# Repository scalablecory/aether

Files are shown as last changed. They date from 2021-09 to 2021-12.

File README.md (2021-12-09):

# Aether



Aether is an air quality monitoring device and software, Open Source and powered by .NET 6.

Want to make your own? Check out the no-soldering-required [Hackathon 2021 build](builds/Hackathon%202021.md), pictured to the right.

## Features

- At-a-glance air quality monitoring with addressable RGB.
- Small standalone device with a custom 3D-printed case.
- No-solder plug-and-play hardware.

### Planned

- SD image for easy deployment.
- Monitor air quality over a Web Bluetooth enabled website.
- Monitor air quality over Bluetooth/WiFi via a .NET MAUI app.
- (Optionally) Join a WiFi network for multi-room monitoring.
- (Maybe) MQTT support.
- (Maybe) Zigbee / LoRa / LoRaWAN support.

## Contributing

Contributions are welcome. Please [contact me](https://github.com/scalablecory) with any questions. The desired workflow is:

1. File an issue describing the bug or desired enhancement.
2. If you intend to perform the work on an issue, ask for it to be assigned to you.
3. If the issue is for an enhancement, wait for it to be approved.
4. File a PR. Make sure to link the issue it will close in the top comment.

Aether could use contributions for:

- Web and mobile dev, for Bluetooth apps.
- Linux deployment (install instructions and/or SD image creation)
- Linux Bluetooth (need to make the Aether into a BLE device)
- Driver dev (C#).
- General .NET dev (C#).
- 3D modeling for case design.

## Hardware Support

- [Raspberry Pi](https://www.raspberrypi.org/) - 3B, 4B, and Zero 2
- [Waveshare 2.9" E-ink display](https://www.waveshare.com/product/displays/e-paper/epaper-2/2.9inch-e-paper-module.htm)
- [Sensirion SCD4x](https://www.sensirion.com/en/environmental-sensors/carbon-dioxide-sensors/carbon-dioxide-sensor-scd4x/) - CO<sub>2</sub>, temperature, relative humidity
- [Sensirion SHT4x](https://www.sensirion.com/en/environmental-sensors/humidity-sensors/humidity-sensor-sht4x/) - temperature, relative humidity
- [Sensirion SPS30](https://www.sensirion.com/en/environmental-sensors/particulate-matter-sensors-pm25/) - PM<sub>0.5</sub>, PM<sub>1.0</sub>, PM<sub>2.5</sub>, PM<sub>4</sub>, PM<sub>10</sub>
- [Sensirion SGP40](https://www.sensirion.com/en/environmental-sensors/gas-sensors/sgp40/) - VOC detector
- [TE MS5637](https://www.te.com/commerce/DocumentDelivery/DDEController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) - barometric pressure
- [Dongguan OPSCO Optoelectronics SK9822](https://www.opscoled.com/en/product/details.html?id=19) - Addressable RGB LED

## .NET Contributions

After being proven in Aether, drivers are contributed to [dotnet/iot](https://github.com/dotnet/iot/). So far, this has been:

- [Sensirion SCD4x](https://github.com/dotnet/iot/tree/main/src/devices/Scd4x) - CO<sub>2</sub>, temperature, relative humidity
- [Sensirion SHT4x](https://github.com/dotnet/iot/tree/main/src/devices/Sht4x) - temperature, relative humidity

# License

Aether is licensed under the [MIT license](https://opensource.org/licenses/MIT).

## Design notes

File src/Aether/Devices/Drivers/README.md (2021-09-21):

# Aether Sensor Drivers

These should be contributed to dotnet/iot repo once completed.

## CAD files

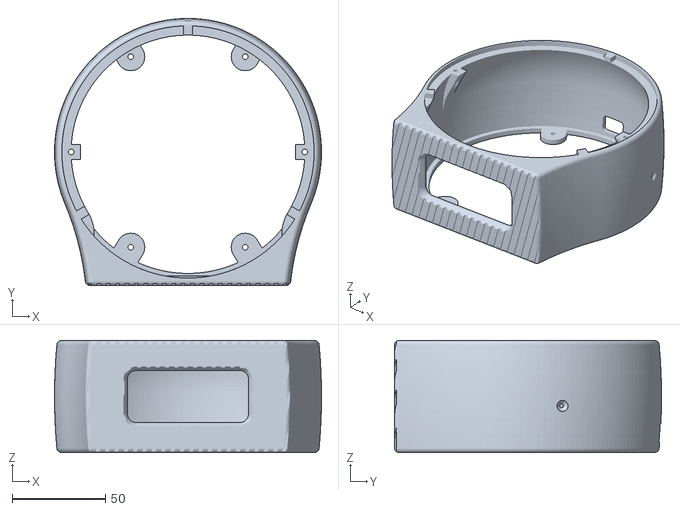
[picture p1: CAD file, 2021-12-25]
builds/Hackathon 2021/Body.stl
142.9 x 143.0 x 60.0

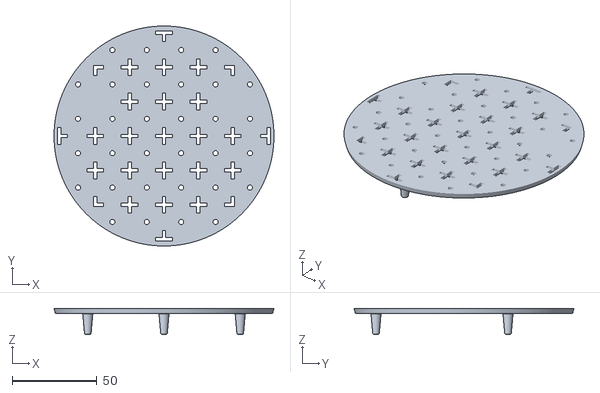
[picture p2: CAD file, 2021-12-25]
builds/Hackathon 2021/Base.stl
130.0 x 130.0 x 15.5

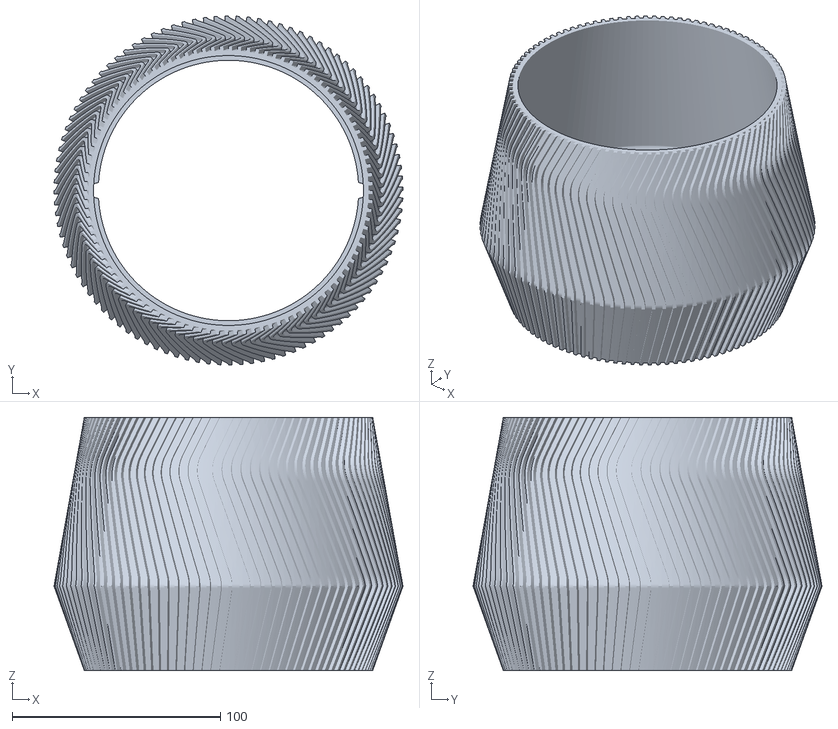
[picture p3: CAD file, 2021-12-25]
builds/Hackathon 2021/Baffle.stl
167.6 x 167.6 x 121.5

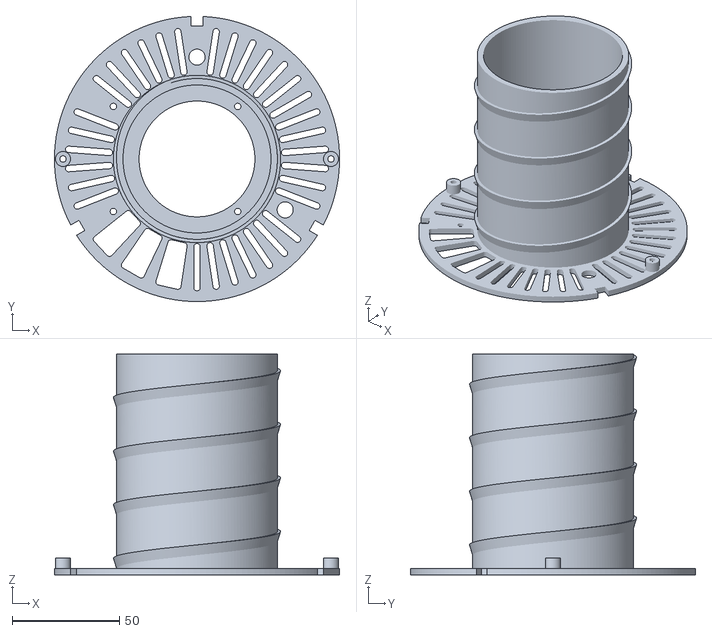
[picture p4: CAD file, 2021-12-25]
builds/Hackathon 2021/Pi holder.stl
133.0 x 132.9 x 103.0

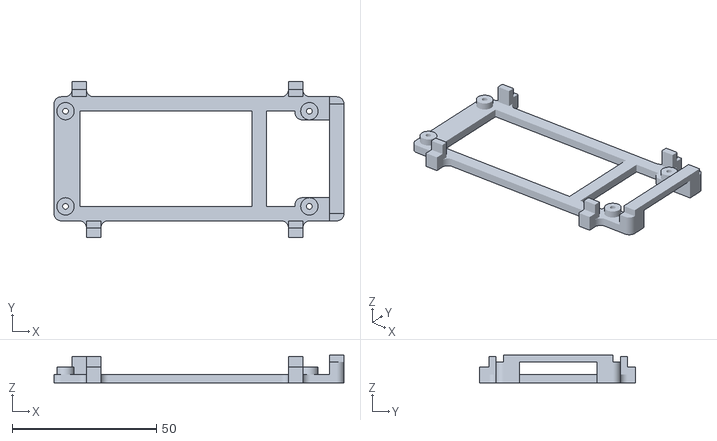
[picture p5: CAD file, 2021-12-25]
builds/Hackathon 2021/Display Bracket.stl
100.5 x 53.9 x 9.70

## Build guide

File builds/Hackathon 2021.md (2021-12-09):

# Hackathon 2021



This was created as part of Microsoft's [2021 Hackathon](https://garagehackbox.azurewebsites.net/hackathons/2356/projects/105003).

See a video of it in action to the right.<br clear="right" />

## Parts List

Parts are chosen to be plug and play, with no soldering required. This build uses the [Qwiic](https://www.sparkfun.com/qwiic) I<sup>2</sup>C wiring system to be very easy to piece together.

Sensors can be left off if uninterested in their measurements.

| Part | Description | Sparkfun Link | Adafruit Link
| ---- | --- | --- | ---
| Raspberry Pi 4 Model B 2GB | Main board. | [SF Pi 4](https://www.sparkfun.com/products/15446) | [AF Pi 4](https://www.adafruit.com/product/4292)
| Sensirion SCD40 | CO<sub>2</sub>, Relative Humidity, and Temperature sensor. | [SF SCD40](https://www.sparkfun.com/products/18365) | [AF SCD40](https://www.adafruit.com/product/5187)
| TE MS5637 | Barometric Pressure and Temperature sensor. Used to calibrate the SDC40. | [SF MS5637](https://www.sparkfun.com/products/14688)
| Sensirion SGP40 | VOC change sensor. | [SF SGP40](https://www.sparkfun.com/products/18345) | [AF SGP40](https://www.adafruit.com/product/4829)
| Sensirion SPS30 | PM<sub>0.5</sub>, PM<sub>1.0</sub>, PM<sub>2.5</sub>, PM<sub>4</sub>, and PM<sub>10</sub> sensor. | [SF SPS30](https://www.sparkfun.com/products/15103)
| [Waveshare 2.9" E-ink](https://www.waveshare.com/product/displays/e-paper/epaper-2/2.9inch-e-paper-module.htm) | A display to show measurements.

### Addressable RGB

To wire the LEDs, some breadboarding or soldering will be required.

Other than the LEDs themselves, these parts do not require software support. Feel free to mix and match.

| Part | Description | Mouser Link | Adafruit Link
| ---- | --- | --- | ---
| SK9822 / APA102C | Addressable RGB LEDs. | [SF APA102C](https://www.sparkfun.com/products/14015) | [AF SK9822](https://www.adafruit.com/product/2239?length=1)
| 3.3v to 5v level shifter, min two inputs | Converts signals from Pi's 3.3v to the LED's 5v. | [Mouser SN74AHCT125N](https://www.mouser.com/ProductDetail/595-SN74AHCT125N) | [AF SN74AHCT125N](https://www.adafruit.com/product/1787)
| Capacitor, min 5V 1000μF | To smooth out power demand of LEDs. | [Mouser ESW108M6R3AH1AA](https://www.mouser.com/ProductDetail/80-ESW108M6R3AH1AA)

## Operating System Setup

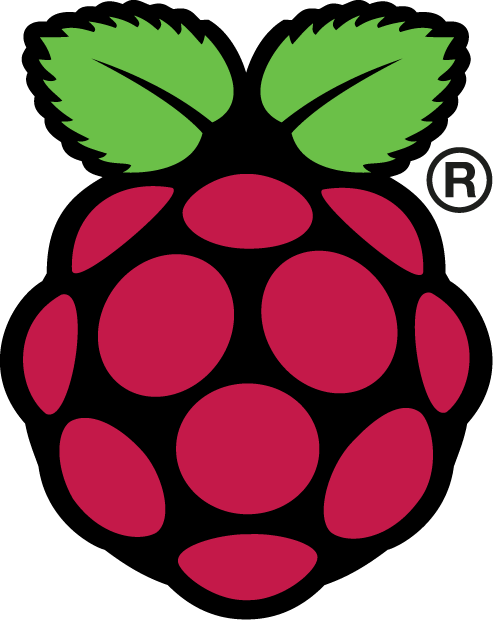
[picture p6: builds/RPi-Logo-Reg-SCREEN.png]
Raspberry Pi logo


Before wiring everything up, lets setup the software.<br clear="left" />

<p>1. <a href="https://www.raspberrypi.com/software/">Flash Raspberry Pi OS to a MicroSD card</a>.</p>

<p>I recommend using the Lite (32-bit) image, though the full Desktop image will work as well.</p>

<p>2. Enable I2C and SPI.</p>

<p>Each GPIO on the Raspberry Pi can have many different functions. We need to enable the I2C1, SPI0, and SPI1 interfaces.</p>

<p>Open config.txt file from the boot partition of the MicroSD card, and find this section of the file:</p>

<pre># Uncomment some or all of these to enable the optional hardware interfaces
#dtparam=i2c_arm=on
#dtparam=i2s=on
#dtparam=spi=on</pre>

And change that section to look like:

<pre># Uncomment some or all of these to enable the optional hardware interfaces
dtparam=i2c_arm=on
#dtparam=i2s=on
dtparam=spi=on

dtoverlay=spi1-1cs,cs0_pin=23</pre>

<p>3. Configure SSH.</p>

<p>To run headless and/or allow you to login to your Pi via SSH, create an empty file with the name "ssh" in the same directory as config.txt.</p>

<p>4. Configure WiFi (Optional).</p>

<p>If you want to connect to the Pi via WiFi, configure it now by adding a file wpa_supplicant.conf to the same directory as config.txt:</p>

<pre>country=US
ctrl_interface=DIR=/var/run/wpa_supplicant GROUP=netdev
update_config=1

network={
ssid="your ssid"
psk="your psk"
key_mgmt=WPA-PSK
}</pre>

## Wiring Instructions

If this is your first time putting together an IoT project with a Raspberry Pi, take some time to get familiar with its GPIO pins:

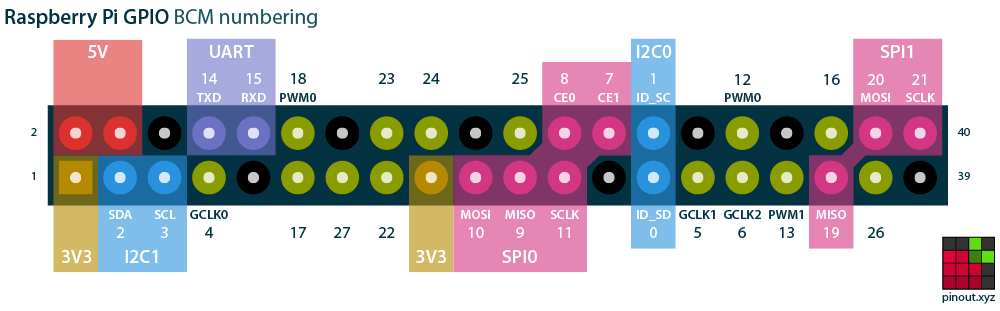
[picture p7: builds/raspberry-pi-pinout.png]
I<sup>2</sup>C, SPI, and other pins Raspberry Pi GPIO pins


It's not as intimidating as it looks, but please take it easy. It's very possible you'll fry your hardware if you hook things up incorrectly.

 The Hackathon 2021 build makes use of large number of these pins, such as:

- 3V3, 5V, and Ground (the black pins), to power things.
- I2C1, to connect Qwiic devices.
- SPI0, to connect the screen.
- SPI1, to connect addressable RGB LEDs.
- Several of the digital pins.

Lets wire things up step by step. You'll want to have several Qwiic cables and some jumper cables available.

### SCD40

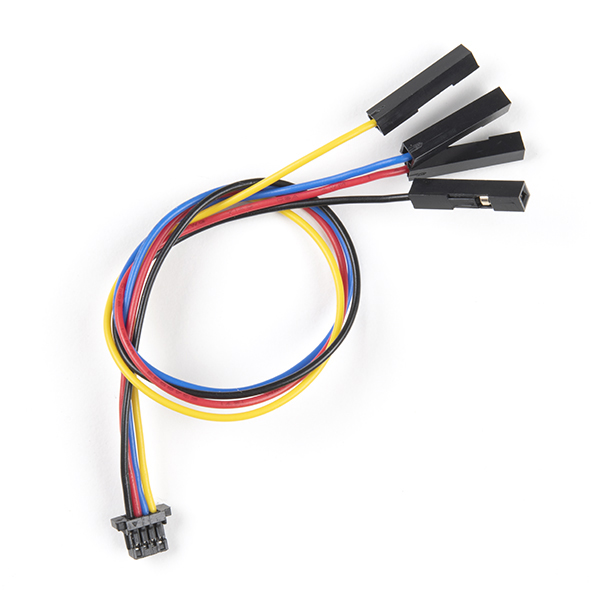
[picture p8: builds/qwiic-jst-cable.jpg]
Qwiic cable with GPIO pin connectors and a JST connector Qwiic cable


<p>1. Grab a Qwiic to Female Jumper cable. The SCD40 runs over I<sup>2</sup>C, and will be connected to I2C1, 3V3, and Ground.</p>

<p>Proceed to the next step to plug it in.</p><br clear="left" />

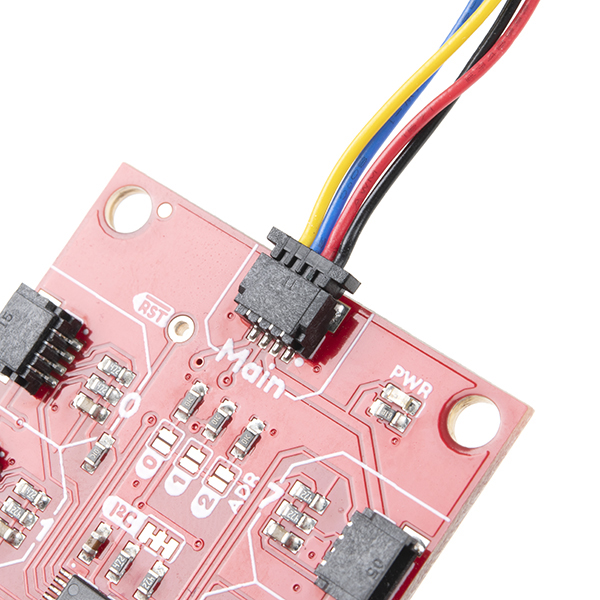
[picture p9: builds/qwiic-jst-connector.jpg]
Qwiic cable connecting to device via JST Qwiic cable connecting to device


<p>2. Connect the JST end of the Qwiic cable to the SCD40.</p><br clear="left" />

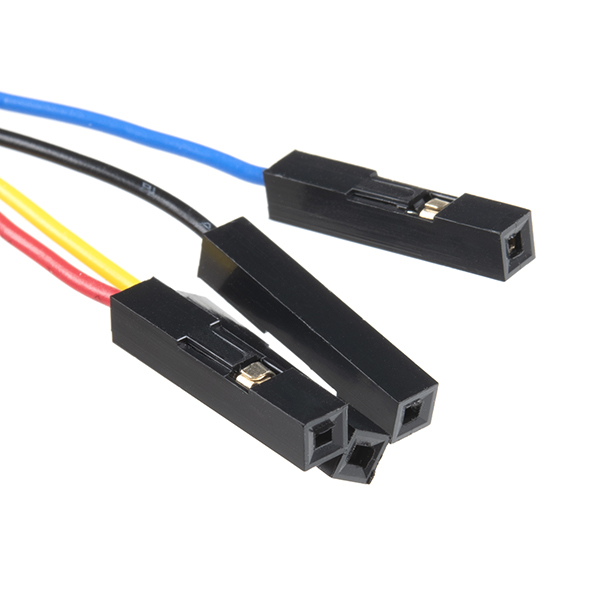
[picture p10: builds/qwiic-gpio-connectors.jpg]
Qwiic cable female jumpbers to connect to Raspberry Pi Qwiic cable female jumpbers


<p>3. Connect the female jumper end of the Qwiic cable to the Raspberry Pi.</p>

<p>The wire is color coded to know which hookup to make:</p>

<ul style="overflow: hidden">
<li>Black = GND (any)</li>
<li>Red = 3V3 (any)</li>
<li>Blue = I2C1 SDA</li>
<li>Yellow = I2C1 SCL</li>
</ul><br clear="left" />

### MS5637

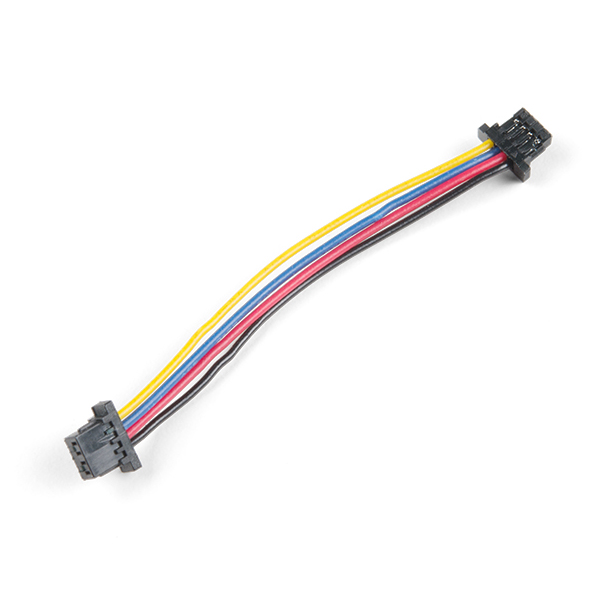
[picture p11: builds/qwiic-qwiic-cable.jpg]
Qwiic cable to connect SCD40 to MS5637 via JST Qwiic device to device cable


<p>4. Time to connect your MS5637. Now grab a Qwiic JST-to-JST cable.</p>

<p>Proceed to the next step to plug it in.</p><br clear="left" />

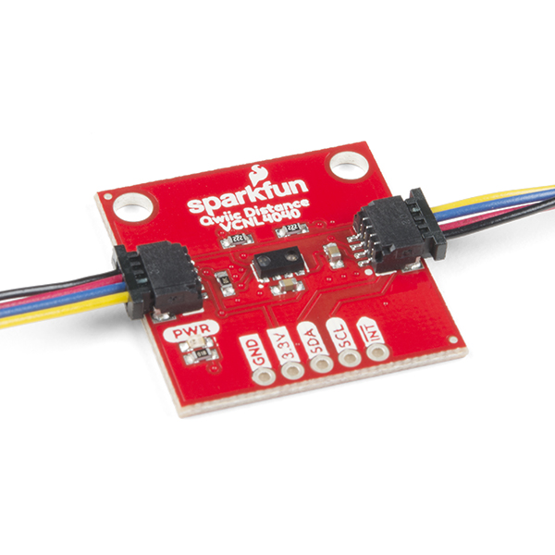
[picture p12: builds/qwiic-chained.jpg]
Qwiic cable connecting a SCD40 to a MS5637 via JST Qwiic device to device connection


<p>5. Plug one end of the cable into the remaining empty JST header on the SCD40.</p><br clear="left" />

Qwiic cable connecting to device via JST Qwiic cable connecting to device

<p>6. Connect the other end of the cable into the MS5637.</p>

<p>Qwiic is designed to be easily chained together, and it doesn't matter which device is connected first or last.</p><br clear="left" />

### SGP40

Qwiic cable connecting a MS5637 to a SGP40 via JST Qwiic device to device connection

<p>7. Repeat the MS5637 instructions, this time chaining the MS5637 to the SGP40.<br clear="left" />

### SPS30

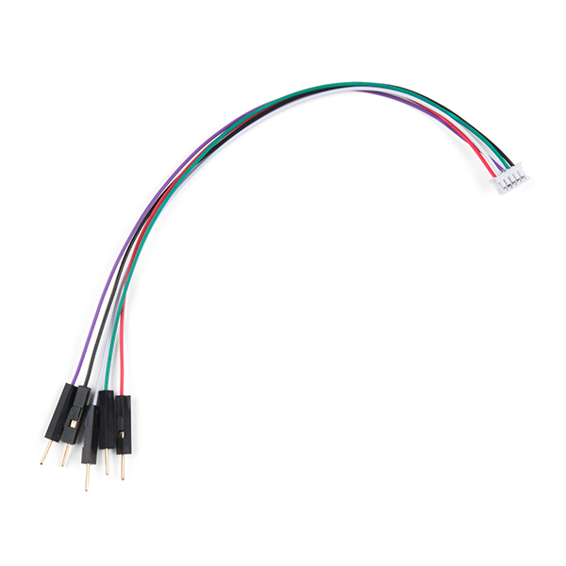
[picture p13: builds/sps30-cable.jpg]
Cable to connect SPS30 to Raspberry Pi via a JST ZHR-5 connector Cable to connect SPS30 to Raspberry Pi


<p>8. Grab the SPS30 cable.</p>

<p>On one side, you have a JST ZHR-5 connector that goes into the SPS30. On the other side are male jumper pins.</p><br clear="left" />

Qwiic cable with GPIO pin connectors and a JST connector Qwiic cable

<p>9. Grab a Qwiic to Female Jumper cable. Connect three of the female jumpers to the SPS30 cable.</p>

<p>The wire is color coded to know which hookup to make:</p>

<ul style="overflow: hidden">
<li>Black (Qwiic cable) = Black (SPS30 cable)</li>
<li>Blue (Qwiic cable) = White (SPS30 cable)</li>
<li>Yellow (Qwiic cable) = Purple (SPS30 cable)</li>
</ul><br clear="left" />

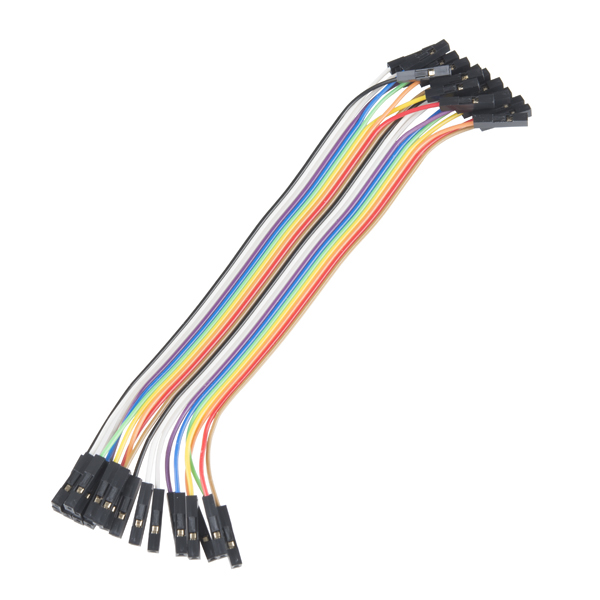
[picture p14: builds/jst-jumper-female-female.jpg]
A bundle of female to female jumper wires Female to female jumper cables


<p>10. Grab two short Female to Female Jumper cables.</p>

<p>These will be used to connect the remaining two SPS30 wires to the Raspberry Pi. The wire is color coded to know which hookup to make.</p>

<ul style="overflow: hidden">
<li>Red = 5V (any)</li>
<li>Green = GND (any)</li>
</ul><br clear="left" />

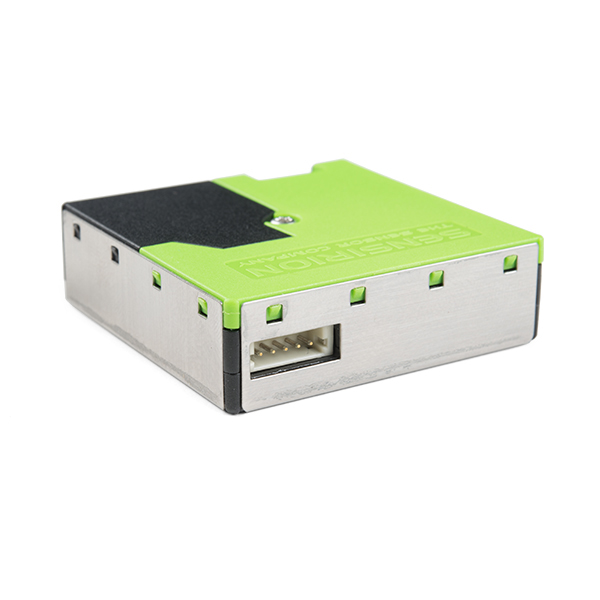
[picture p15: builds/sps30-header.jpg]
The JST ZHR-5 header on the SPS30 JST ZHR-5 header to connect cable to SPS30


<p>11. Connect the JST ZHR-5 connector from your SPS30 cable to the header on the SPS30.</p>

<p>If the connector seems loose, it may not be plugged in all the way.</p><br clear="left" />

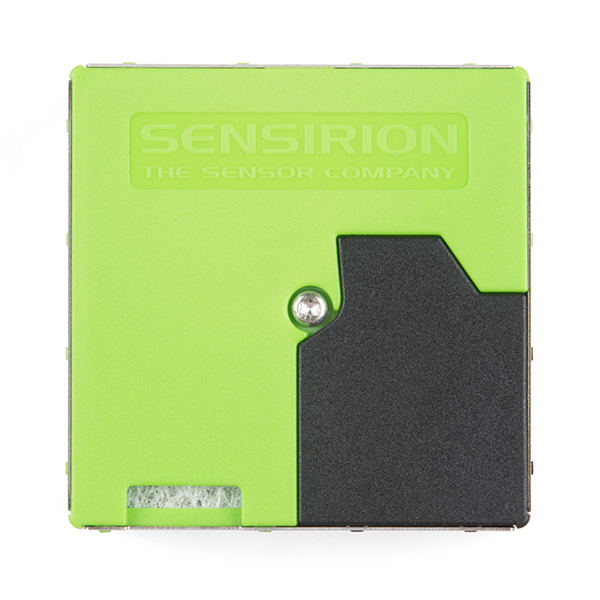
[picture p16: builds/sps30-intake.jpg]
The intake of the SPS30 SPS30 intake


<p>When mounting the SPS30, take care to give the intake (with its fibrous filter) good access to air.</p><br clear="left" />

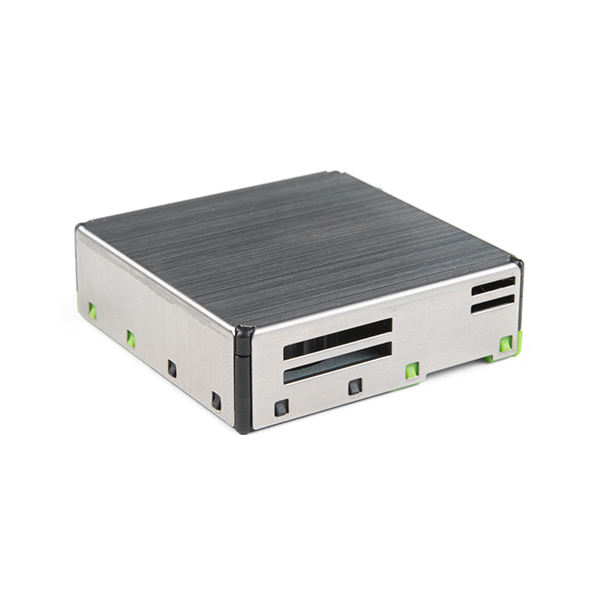
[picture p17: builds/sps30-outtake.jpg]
The outtake of the SPS30 SPS30 outtake


<p>When mounting the SPS30, take care to give four outtake holes good access to air.</p>

<p><b>Important:</b> The metal sides of the SPS30 are connected to ground. Be sure it is not touching any conductors, or a short circuit may destroy your devices.</p><br clear="left" />

### 2.9" E-Paper Display

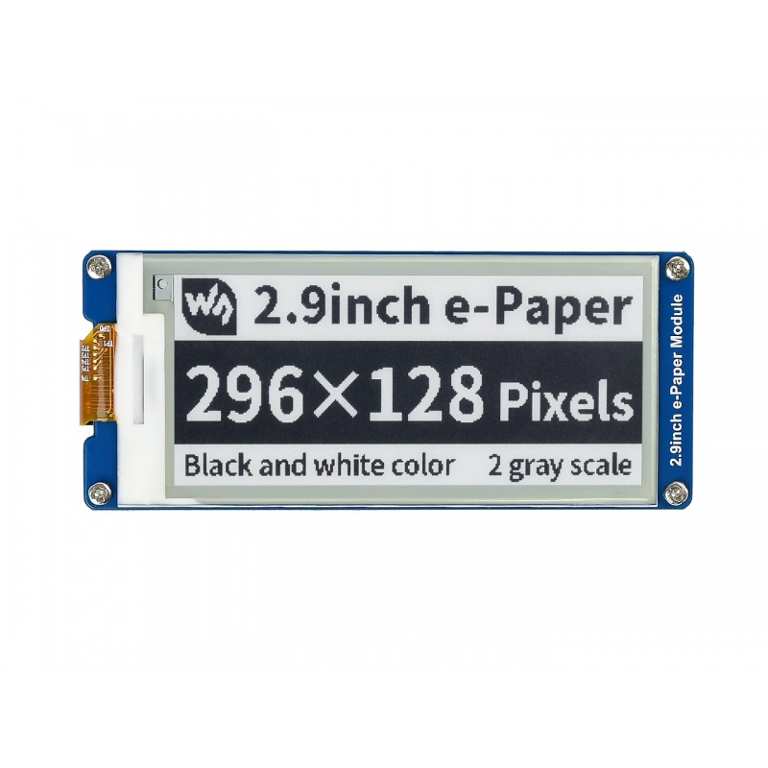
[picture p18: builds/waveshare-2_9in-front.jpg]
The Waveshare 2.9" E-Paper Display The 2.9" E-Paper Display


<p>12. Lets install the 2.9" E-Paper Display.<br clear="left" />

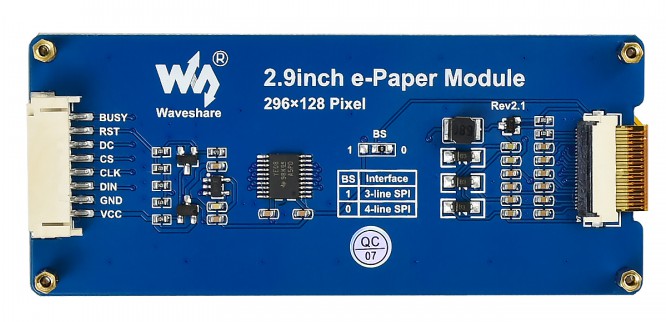
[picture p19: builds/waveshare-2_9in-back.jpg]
The connectors of the 2.9" E-Paper Display The rear of the 2.9" E-Paper Display
<p>Observe the ordering of the pins on the rear left header of the 2.9" E-Paper Display:</p><br clear="left" />

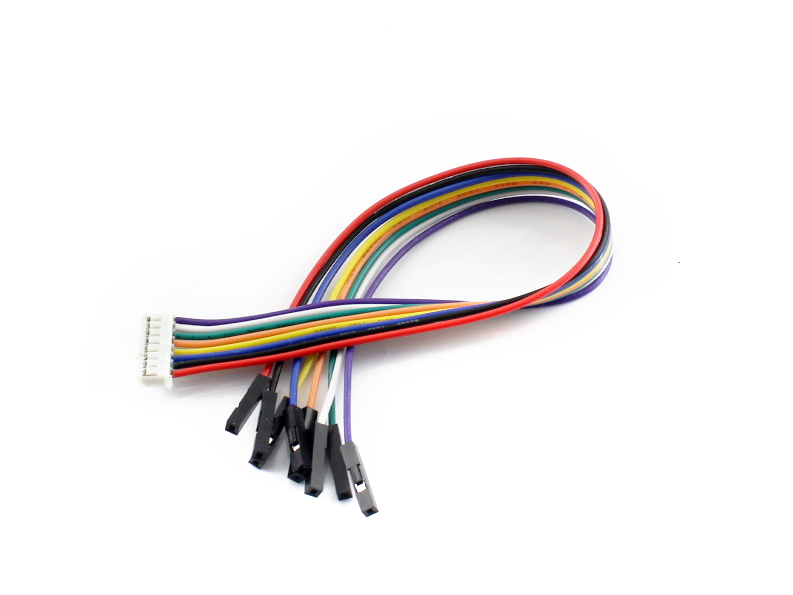
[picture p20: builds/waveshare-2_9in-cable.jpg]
The cable used to connect the 2.9" E-Paper Display to the Raspberry Pi Cable for the 2.9" E-Paper Display


<p>13. Grab the SPS30 cable.</p>

<p>Connect the cable to the 2.9" E-Paper Display module. Connect the other end to the Raspberry Pi. The wire is color coded to know which hookup to make, but double check with the labels on the back in case they change the colors:</p>

<ul style="overflow: hidden">
<li>VCC = 5V (any)</li>
<li>GND = GND (any)</li>
<li>DIN = SPI0 MOSI</li>
<li>CLK = SPI0 SCK</li>
<li>CS = CE0</li>
<li>DC = 25</li>
<li>RST = 17</li>
<li>BUSY = 24</li>
</ul><br clear="left" />

### LEDs

To connect LEDs, soldering a protoboard is recommended. A breadboard may not be able to handle the power requirements.

TODO

## Aether Software Setup

Raspberry Pi logo

<p>1. Connect to your Raspberry Pi.</p>

<p>If you're running headless, SSH into the Pi remotely. Otherwise, connect a screen/keyboard, login, and open a terminal.</p>

<p>The default username and password for a Raspberry Pi are "pi" and "raspberry".</p><br clear="left" />

<p>2. Install .NET 6</p>

<p>Follow the <a href="https://docs.microsoft.com/en-us/dotnet/core/install/linux-scripted-manual#scripted-install">.NET 6 Install instructions</a>.</p>

<p>3. Clone Aether</p>
<pre>git clone https://github.com/scalablecory/aether.git
cd aether/src/Aether</pre>

<p>4. Edit Program.cs</p>

<p>Modify the main command handler based on the hardware you installed. You may need to tweak pin numbers if you didn't wire things exactly the same, or set a different pixel count if you installed addressable RGB.</p>

<p>TODO: replace this step with modifying a config file?</p>

<p>5. Run Aether</p>

<pre>dotnet run -c Release -- run-device</pre>

## Copyright Notice

Images &copy; their respective owners. Images &copy; SparkFun are [CC BY 2.0](https://creativecommons.org/licenses/by/2.0/).

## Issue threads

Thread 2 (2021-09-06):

Bluetooth UI

scalablecory, 2021-09-06:
An Aether device should act as a Bluetooth device. Its UI will show time-based charts and allow administering of the device.

This will consist of:

- A static website, to be hosted on Github Pages, that will use Web Bluetooth to connect with the Aether device.
- A Bluetooth API.
- A physical switch to enter pairing mode, with any relevant pairing codes displaying on-screen.

## Features

- A fully static website, no data transmitted over the net.
- Configuration:
     - Select sensors, displays, assign dependencies.
     - Recording settings (how long of a history to record, etc.)
     - Connectivity (Wifi, LoRa) settings.
- Charts:
    - One for each measure.
    - Show charts of other devices in the network (if not a standalone device).

Closed 2021-09-22.

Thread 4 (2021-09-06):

Wi-Fi connectivity

scalablecory, 2021-09-06:
Aether should be able to connect over Wi-Fi, allowing the Bluetooth UI (#2) to display all the sensors on the same network.

Ideally there would be two options:
- Connect to an existing Wi-Fi network.
- Mesh Wi-Fi. It's not clear if the Pi's antenna will be able to support this.

Connecting to Wi-Fi means attaching a full Linux system to what might be the internet, and what might be a network with a bunch of the user's devices. There should be some strategy to keep the software updated.

A mesh Wi-Fi would largely bypass security concerns by separating any Aether devices to their own private network. There are, of course, range tradeoffs.

Closed 2021-09-22.

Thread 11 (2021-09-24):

Sensirion SGP40 driver

scalablecory, 2021-09-24:
Aether needs a driver and sensor code for [Sensirion's SGP40](https://www.sensirion.com/en/environmental-sensors/gas-sensors/sgp40/).

The device is purchasable from [Sparkfun](https://www.sparkfun.com/products/18345). It can be purchased from elsewhere, however Build A will have mounting points specifically for Sparkfun's Qwiic breakout dimensions.

CrispyBit, 2021-10-09:
I can try this.

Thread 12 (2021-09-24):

Adapt existing drivers for Aether

scalablecory, 2021-09-24:
The Iot.Device.Bindings library from [dotnet/iot](https://github.com/dotnet/iot) supports some sensors that are applicable to Aether. `ObservableSensor` implementations of these should be built.

Good candidates are:
- [BMxx80](https://github.com/dotnet/iot/blob/main/src/devices/Bmxx80/README.md) temperature, relative humidity, barometric pressure, VOC sensor.
- [MH-Z19B](https://github.com/dotnet/iot/blob/main/src/devices/Mhz19b/README.md) CO<sub>2</sub> sensor
- [CCS811](https://github.com/dotnet/iot/blob/main/src/devices/Ccs811/README.md) VOC sensor

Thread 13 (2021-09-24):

Design Build B

scalablecory, 2021-09-24:
Build B is intended to be more cost effective, but may require more electrical knowledge, soldering, and/or breadboards to hook up.

This issue is to add a [build](builds/) with off-the-shelf parts that will all work together.

Upon PR approval, issues should be added to create drivers for any new parts.

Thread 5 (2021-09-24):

Configuration system

scalablecory, 2021-09-24:
Aether requires a configuration system. It must be able to save to a file to survive reboots.

This would describe things like:

- What sensors are enabled.
    - I<sup>2</sup>C/etc. addresses.
    - Dependencies.
- What displays are enabled.
    - SPI/etc. addresses.
    - Which theme to use, and what measurements/sensors to use in the theme.

AkwasiAkosah, 2021-10-13:
In the process of initializing a giving sensor, is it safe to assume that the user knows information about the address of the device, name and other properties needed to establish the communication? Are we using any pre-made methods?

scalablecory, 2021-10-13:
https://github.com/scalablecory/aether/blob/6df481eb006a4534c450b12e409655d4bf9aab6e/src/Aether/Devices/Sensors/Metadata/SensorInfo.cs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

https://github.com/scalablecory/aether/blob/6df481eb006a4534c450b12e409655d4bf9aab6e/src/Aether/Devices/Sensors/Metadata/I2cSensorInfo.cs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

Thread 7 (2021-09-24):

Bluetooth Listener

scalablecory, 2021-09-24:
Aether needs to configure the device to act as a BLE device, listening for connections from phones.

The Bluetooth protocol itself will be a wrapper around the [Control API](https://github.com/scalablecory/aether/issues/6).

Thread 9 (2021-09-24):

Case for Build A

scalablecory, 2021-09-24:
A 3D printable case is needed for [Build A](https://github.com/scalablecory/aether/blob/main/builds/a.md).

The Raspberry Pi should be isolated from the sensors, to avoid the Pi's high temperatures from affecting sensor accuracy.

The case should have good but not turbulent ventilation over sensors, and protect them from direct light. Ideally, it would follow any airflow directions outlined in the sensor data sheets (Sensirion has very specific details here).

scalablecory, 2021-10-11:
Dims for the standard Qwiic 1" breakout. The mounting holes are compatible with 4-40 screws e.g. https://www.sparkfun.com/products/10453 and https://www.sparkfun.com/products/10463.

This is for the [SCD40](https://www.sparkfun.com/products/18365) and [SGP40](https://www.sparkfun.com/products/18345).

**Note**, the [MS5637](https://www.sparkfun.com/products/14688), [BME680](https://www.sparkfun.com/products/16466), and some others that I've seen are the same but only have two mounting holes. For future compat it may be good to ensure any 2-hole sensors can mounted.

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

scalablecory, 2021-10-11:
Dims for SPS30:

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

Avoid obstructing the intake/outtake and wires:

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

mrleemurray, 2021-10-12:
I have found this ambient light sensor from Adafruit that is QWIIC compatible: https://www.adafruit.com/product/4681
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

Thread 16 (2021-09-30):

RGB driver

scalablecory, 2021-09-30:
Need to find some addressable RGB LEDs to act as a "display" for Aether.

The LEDs:
   - Should work well on a Pi (e.g. "NeoPixel" and others needing super high PWM rates might not work).
   - Flexible, chainable strips.

The power supply:
   - Should power all of the hardware, not just LEDs.

And finally code a display driver for them.

scalablecory, 2021-10-10:
These might work:

https://www.amazon.com/BTF-LIGHTING-Individually-Addressable-Non-Waterproof-Separately/dp/B07BPX2KFD/

The high density would allow for smoother animations. 12mm width might restrict the design a little bit.

Closed 2021-10-31.

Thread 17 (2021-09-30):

Light sensor driver

scalablecory, 2021-09-30:
To support the RGB LEDs in #16, Aether needs a light sensor that can ensure the LEDs match their environment without getting too bright or too dark.

This issue is to find which hardware to use, and also write a driver for it.

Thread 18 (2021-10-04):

Glue layer

scalablecory, 2021-10-04:
A layer is needed to combine:

- Instantiating a sensor/display graph based on [configuration](https://github.com/scalablecory/aether/issues/5).
- Starting up the [Control API](https://github.com/scalablecory/aether/issues/6) and managing when it changes config.

scalablecory, 2021-10-16:
Here's a general architectural outline to help plan this:
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

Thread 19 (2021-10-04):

Basic theming abstraction

scalablecory, 2021-10-04:
An abstraction is needed for theming. A theme is in charge of taking various sensor measurements and rendering them to a display driver.

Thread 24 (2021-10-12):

Database layer

scalablecory, 2021-10-12:
A database sink is needed to efficiently record sensor data out of an `IObservable<Measurement>`.

It needs to be seekable by date/time to support the [control API](https://github.com/scalablecory/aether/issues/6).

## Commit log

2021-08-23 Rework observable sensor design.
2021-08-30 Get SCD4x and SHT4x sensors working; start on MS5637.
2021-09-01 Flush out SHT4x features a little bit. Add simulated MS5637 device. Rework ObservableSensor innards.
2021-09-05 Add a simulate sensor command.
2021-09-06 Fix timing of observable sensors, and SimulatedMS5637 implementation.
2021-09-19 Refactor/rename sensors to bring more in line with dotnet/iot and prep for move to there.
2021-09-24 Add Measurement struct, adjust sensors to use it.
2021-10-14 e-ink driver. (#25)
2021-10-15 Add some hard-coded full hardware device code. Fix two of the sensors not starting their loop.
2021-10-16 SGP4x driver and VOC Index Algorithm C# port (#22)
    Add SGP4x sensor
2021-10-19 Aether's SHT4x and SCD4x drivers were contributed into dotnet/iot in https://github.com/dotnet/iot/pull/1668. Depend on those now.
2021-10-29 Adding SPS30 device driver (#29)
    Add SPS30 driver, closing #10.
2021-10-31 Add SK9822 addressable RGB LED driver. (#30)
    Add concept of BufferedDisplayDriver.
    Add RgbTheme.
2021-11-08 Add horizontal theme to fit Hackathon case. (#31)
    Discovered weird initialization order issue with SPS30; worked around for now.
    Fix some misc styling things.
2021-12-01 Make RGB theme animate. Make RGB drivers different from display drivers.
2021-12-09 fix an off-by-one error causing bright LEDs to go dark.
2021-12-25 Add per-pixel addressable RGB LED support.
2021-12-25 Add 3D printing files.
    [Baffle.stl, Base.stl, Body.stl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]
2022-01-28 Simplify sensor factory.
